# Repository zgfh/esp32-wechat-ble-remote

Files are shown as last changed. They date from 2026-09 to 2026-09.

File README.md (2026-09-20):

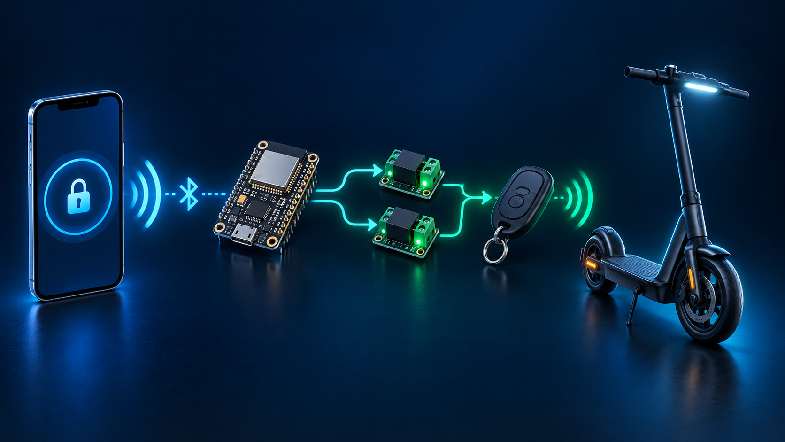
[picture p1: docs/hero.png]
微信小程序通过 BLE 控制 ESP32、光耦和电动车遥控器


<h1 align="center">电动车手机遥控钥匙</h1>
<p align="center"><strong>低成本、低复杂度：微信小程序 → BLE → ESP32 → 光耦 → 原装遥控器 → 电动车</strong></p>


> [!WARNING]
> 仅用于你有权控制的设备。项目只模拟原遥控器物理按键，不读取、复制或重放射频码；请勿接入一键启动等高风险功能。

## 你可能遇到的问题

你希望不用天天带物理遥控钥匙，却又不想拆解、复制或研究车辆的射频协议。若电动车后备箱本身是密码锁，可把这套设备与原遥控器一起放进后备箱：出门只带手机，需要时用小程序控制车辆。

本项目只做一件事：**以低成本、低复杂度保留原装遥控器的编码和发射能力，让 ESP32 通过光耦模拟真人短按。**

| 常见做法 | 本项目 |
| --- | --- |
| 复制或重放 RF，易遇滚动码问题 | 原遥控器继续处理 RF |
| ESP32 与遥控器共地 | 每个按键独立光耦隔离 |
| 蓝牙一连接就自动开锁 | 明确点按，避免瞬断误动作 |
| 设备名或 MAC 作为身份 | HMAC、随机挑战、序号防重放 |

### 推荐放置方式

```text
后备箱（密码锁）
├── 原装遥控器：仍负责滚动码和 RF 发射
└── ESP32 + 4 路光耦：由独立电源供电，连接遥控器按键焊盘

随身携带
└── 手机：微信小程序近距离 BLE 控制
```

后备箱密码是物理访问的第一道保护；请设置独立、可靠的密码，并妥善固定 ESP32 和遥控器，避免行驶震动导致接线松脱。

## 工作架构

完整工作原理图：手机、BLE、ESP32、光耦、原装遥控器和电动车

```mermaid
flowchart LR
  phone["📱 微信小程序\n输入密码 · 发起控制"] -->|"BLE"| esp["ESP32\nHMAC 验证 · 180 ms 脉冲"]
  esp -->|"GPIO 26 / 27 / 25 / 33"| opto["4 × PC817 光耦\n电气隔离"]
  opto -->|"模拟实体按键"| fob["原装遥控器\n滚动码 · RF 发射"]
  fob -->|"原装无线信号"| scooter["🛵 电动车"]
```

支持四路短按：**锁车、解锁、启动（闪电键）、寻车（喇叭键）**；同一时刻只允许一路输出。手机就是日常遥控入口，原装遥控器保留在后备箱内。

> 想了解信号边界、后备箱放置方式和安全部署顺序？阅读 [工作原理与部署指南](docs/working-principle.md)。

## 三分钟上手

### 1. 接线

每个按键使用独立 PC817：GPIO 经 330 Ω 接光耦 LED 输入；晶体管侧跨接遥控器对应的两块焊盘。

| 动作 | 普通 ESP32 | ESP32-S3 |
| --- | ---: | ---: |
| 锁车 | GPIO 26 | GPIO 4 |
| 解锁 | GPIO 27 | GPIO 5 |
| 启动 | GPIO 25 | GPIO 6 |
| 寻车 | GPIO 33 | GPIO 7 |

详细接线与测量方法见 [固件接线指南](firmware/README.md#接遥控器，同时保留-led当前接线图)。**遥控器侧绝不能与 ESP32 GND 相连，也不要用其纽扣电池为 ESP32 供电。**

### 2. 修改默认密码

[`firmware/pairing_config.py`](firmware/pairing_config.py) 的默认密码是 `dangerous`，仅供联调，公开可见且不安全。刷入前务必按需修改：

```python
BLE_PAIRING_SECRET = "替换为至少 32 位随机长密码"
```

随后在小程序密码框输入同一密码；密码不写入小程序源码或日志。这样即使有人在附近发现设备，也不能直接发送控制命令。

### 3. 刷入与连接

1. 上传 `firmware/main.py`、`firmware/security.py`、`firmware/pairing_config.py` 到 ESP32 MicroPython 根目录。
2. 微信开发者工具导入 [`miniprogram/`](miniprogram/)，真机预览并允许蓝牙/附近设备权限。
3. 连接 `ESP32-Car-Remote`，认证成功后使用按钮。

> 微信开发者工具不能模拟 BLE，必须在真实手机验证。

### 推荐：让 AI 协助安装、部署和运行

可把仓库链接、ESP32 板型和遥控器按键照片交给可信 AI 编程代理，让它协助检查引脚、生成随机密码、上传文件、运行测试和解释串口日志。

请明确要求 AI：**不提交真实密码、不猜测遥控器焊盘、未获确认前不触发车辆控制**。详见 [部署指南](docs/working-principle.md#推荐让-ai-协助部署)。

## 安全模型

```mermaid
sequenceDiagram
  participant P as 📱 小程序
  participant E as ESP32
  P->>E: HELLO2
  E-->>P: CHALLENGE2: 随机 nonce
  P->>E: AUTH2: HMAC(secret, nonce)
  E-->>P: AUTH_OK
  P->>E: CMD2: 序号 + 动作 + HMAC
  E-->>P: OK: 动作已接受
```

- 每连接独享挑战与认证，15 秒未认证自动断开。
- 每条命令绑定会话、动作和递增序号，防篡改与重放。
- 连续失败会冷却；5 分钟无操作自动断开。
- HMAC 不等同车规数字钥匙；更高要求应加入 BLE 加密、硬件安全元件和距离测量。

## 项目结构与测试

```text
firmware/       ESP32 MicroPython、接线资料、3D 外壳、回归测试
miniprogram/    微信小程序与 HMAC 安全测试
docs/hero.png   README 主视觉图
```

```bash
python3 -m unittest discover -s firmware/tests
node miniprogram/tests/security.test.js
```

## License

[MIT](LICENSE)

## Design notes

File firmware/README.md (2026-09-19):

# ESP32 BLE 遥控器控制端

> **安全协议 v2（已部署到普通 ESP32）**：必须同时更新 ESP32 的 `main.py`、`security.py` 和小程序代码，保留原有本地配对配置。旧 HELLO/AUTH/CMD 明文协议已停用；下方历史调试记录中的旧协议不能用于新版。

ESP32 通过 GPIO 输出（ESP32-S3：4/5/6/7；普通 ESP32：26/27/25/33） 180 ms 脉冲，驱动四个光耦，模拟原车遥控器的锁车/解锁/启动/寻车实体按键。它不会读取、复制或重放射频编码；遥控器仍完成原有编码和发射。

## 接遥控器，同时保留 LED（当前接线图）

VS Code 按 **⌘⇧V** 预览。以下适用于裸四脚 PC817，GPIO 编号按板上丝印识别。

四路遥控器按键与保留 LED 的隔离接线图

| 功能 | ESP32-S3 | 旧 ESP32 | 遥控器按键 |
| --- | --- | --- | --- |
| 锁车 | GPIO4 | GPIO26 | 锁车 / 设防 |
| 解锁 | GPIO5 | GPIO27 | 解锁 / 解防 |
| 启动 | GPIO6 | GPIO25 | 闪电键 |
| 寻车 | GPIO7 | GPIO33 | 喇叭键 |

每路 GPIO 分成两条并联支路：**GPIO → 330Ω → PC817 的 1 脚，2 脚 → ESP32 GND**；另一路 **GPIO → 独立 330Ω → 红色 LED 长脚，LED 短脚 → ESP32 GND**。不要让 LED 与光耦输入串联，也不要共用一个限流电阻。共需 4 颗 PC817、4 颗 LED、8 只 330Ω；建议各 GPIO 另加 10kΩ 到 GND。

**现有 LED 保留，但要从光耦输出侧移到 GPIO 侧。** 将光耦 3、4 脚原来接到 ESP32 GND / 3V3 / LED 的线路全部断开，再接遥控器；否则会破坏隔离。

### 圆形触点的测量方法与接线

照片中的每个按键由**中心圆点**和**外侧 C 形金属环**组成；按下时将两者接通。不能仅凭形状判断正负，也不能默认外圈是负极。

**本次用户实测：红表笔接中心、黑表笔接外圈，电压显示为正。因此已测按键的中心接 PC817 4 脚（集电极 C），外圈接 PC817 3 脚（发射极 E）。** 这里的“4 脚”是光耦脚号，不是 ESP32 GPIO4。该结论只针对已测触点，其他按键分别测量后再接。

1. **先断开 ESP32。** 遥控器只用原电池供电，不连接 ESP32 的 GND 或 3V3。
2. 万用表黑表笔插 **COM**，红表笔插 **VΩ**（不是电流插孔）；选择 **直流电压 V⎓**，量程高于电池标称电压，或使用自动量程。
3. 遥控器装好电池，按键保持松开。**红表笔接中心圆点，黑表笔接外圈 C 形环**。避免表笔同时碰到中心和外圈，以免模拟按键动作。
4. 根据下表确认接线。如果接近 0V、读数不稳定或正负跳变，先不要猜接，需要进一步确认电路或扫描方式。
5. 记录每个按键结果，**取下电池后再焊接**。两根线分别接中心和外圈，保留原按键；不要用焊锡把中心与外圈连在一起，也不要让线材妨碍原按键接触。

| 红笔中心、黑笔外圈时的读数 | PC817 4 脚（C）接 | PC817 3 脚（E）接 |
| --- | --- | --- |
| 稳定正数，例如 +3.0V（本次实测方向） | 中心圆点 | 外圈 C 形环 |
| 稳定负数，例如 −3.0V | 外圈 C 形环 | 中心圆点 |
| 接近 0V 或正负跳变 | 暂不接线，继续检查 | 暂不接线，继续检查 |

表中电压仅为示例，本次只确认了正负方向，未记录具体伏数。图中的 A 表示相对正端，B 表示相对负端；对本次已测按键，**A＝中心，B＝外圈**。三个按键各用独立 PC817，不能假定共用负端。LED 只证明 GPIO 发出指令，不代表光耦输出或车辆动作已经成功。

如果换成四脚机械按键：先取下电池，再用通断档找出“松开断路、按下导通”的两个有效触点；之后装电池，用直流电压档判断极性。**不要在带电时用通断档测量。**

PC817 脚号依据 [Sharp 数据表](https://www.learnabout-electronics.org/Downloads/PC817-optocoupler.pdf)。

<details><summary>旧版：仅 LED 测试接线图（不能直接并入遥控器）</summary>

旧测试线路

这张旧图将 LED 接在光耦输出端，输出侧使用 ESP32 电源，仅供无遥控器时测试。接遥控器请改为上方新图。

</details>

## BLE 协议与使用

1. 仓库随附 `pairing_config.py`，其默认密码 `dangerous` 仅供联调；用于真实设备前，必须按需改为至少 32 字符的随机密码。用户在小程序密码框输入相同内容。密码不再放入小程序源码或安装包。
2. 小程序扫描 `ESP32-Car-Remote`，连接服务 `6e400001-b5a3-f393-e0a9-e50e24dcca9e` 后订阅状态特征。
3. 小程序订阅成功后写入 `HELLO`；ESP32 对该连接发送 `CHALLENGE:<nonce>`。小程序写入 `AUTH:SHA256(secret:nonce)`，收到 `AUTH_OK` 后才发送 `CMD:LOCK` 或 `CMD:UNLOCK`。

挑战码和认证状态均按 BLE 连接隔离；断开连接后认证立即失效。设备应安装在受保护位置，且不应把默认示例密钥投入使用。

## Wokwi

图中 旧 ESP32 的 GPIO 26/27 各接一只 330 Ω 电阻和 LED，方便观察短按脉冲；实物请以光耦代替 LED。

协议现在以换行符结束每条消息，双向每包最多 20 字节，固件与小程序必须一起更新。认证挑战使用随机数且一次有效；默认占位密钥拒绝认证；三路按键不能同时输出。手机按钮的“已发送”仅表示 ESP32 接受指令，不代表车辆已经上锁。

本地主机回归测试：`python3 remote-key-web-controller/tests/test_protocol.py`（仓库根目录）。
2026-09-19 已经通过串口读取实物为 ESP32_GENERIC / MicroPython 1.28.0；这不代表新固件已刷入或手机 BLE 已验证。

## ESP32-S3 N8R2 实机刷写记录（2026-09-19）

- 串口：`/dev/cu.usbmodem1411201`；芯片 ESP32-S3 revision v0.2。
- 实测 Flash 8MB；内置 Quad PSRAM 2MB，固件识别成功。
- 已刷官方 `ESP32_GENERIC_S3-20260824-v1.29.0.bin` 标准版（不是 Octal PSRAM 版），写入地址 0，Flash 大小设置 8MB，写入哈希校验通过。
- 原 Flash 备份保存在本机 `/Users/zzg/.local/share/esp32-backups/20260919-s3/original-flash.bin`，不应公开上传。
- 已上传本项目 `main.py`；S3 自动使用 GPIO4 锁车、GPIO5 解锁，初始电平均为 0。BLE 初始化、GATT 注册和重启自动启动已实机验证。
- 后续已配置两端本地配对密钥，GPIO4 的 PC817 + LED 三次脉冲测试已由用户确认；手机 BLE 配对仍在调试中，尚未验证遥控器。
- 固件来源：https://micropython.org/download/ESP32_GENERIC_S3/
- S3 引脚限制：https://docs.espressif.com/projects/esp-idf/en/latest/esp32s3/api-reference/peripherals/gpio.html

## VS Code 串口日志

打开仓库根目录，按 **⌘⇧B** 运行 `ESP32: 重启程序并查看串口日志`。任务会自动选择唯一的 Espressif USB 串口，软重启程序并持续显示日志。若上一次日志任务仍在运行，先在其终端按 Ctrl+C 退出，再按快捷键重新启动。日志同时保存在根目录 `simulation-logs/esp32-日期-时间.log`。按 Ctrl+C 退出监视，板上程序继续运行。刷写前先关闭此任务，避免串口占用。

只想监听、不重启时，在“终端 → 运行任务”中选择 `ESP32: 查看串口日志（不重启）`。默认快捷键的重启操作会断开 BLE；随后的 `KeyboardInterrupt` 是工具主动中断旧程序的预期输出，等到 `BLE ready` 即表示重新启动成功。

启动成功显示 `BLE ready: ESP32-Car-Remote`；手机连上显示 `BLE: connected`；收到握手显示 `BLE: HELLO received`；验证成功显示 `BLE: authentication OK`。日志不输出配对密钥、挑战码或认证摘要。

小程序日志在微信开发者工具的真机调试 Console 中，筛选 `[BLE]`。`openBluetoothAdapter:fail` 表示手机蓝牙初始化失败，还没开始扫描 ESP32；记录 errCode、errno、errMsg 和 permission/system 日志再判断原因。代码更新后需重新加载手机测试版本。

### 增强诊断日志

日志前缀 `[ESP32 t=...ms]` 使用板子的运行计时，外层 `[时:分:秒]` 是电脑接收时间。

| 日志 | 含义 |
| --- | --- |
| BOOT / GPIO_READY | 板型、固件版本、重启原因、GPIO 和初始输出 |
| PAIRING_CONFIGURED True | 已配置配对密钥（不显示密钥） |
| BLE_ACTIVE / GATT_READY | BLE 开启与服务注册完成 |
| ADVERTISE_STARTED | 广播启动调用成功；不代表手机已扫描到 |
| HEARTBEAT | 每 10 秒输出 BLE 状态、连接数、认证数、空闲内存和 GPIO 电平 |
| CONNECTED / DISCONNECTED | 手机建立或断开连接 |
| RX_FRAGMENT / HELLO_RECEIVED | 收到分包长度和握手，不显示内容 |
| AUTH_OK / AUTH_FAILED | 认证结果 |
| NOTIFY_FAILED | 通知发送失败及错误码 |
| BUTTON_ON / BUTTON_OFF | 输出开始及释放，仅表示 GPIO 动作 |

连接数持续为 0 表示当时没有手机连入，不等于广播故障。日志队列最多 64 条，满后记录丢弃数；按键输出期间暂停打印，避免串口打印延迟释放。查看旧的“BLE: ...”阶段说明时，以这里的大写事件名为准。

## 启动（闪电键）

小程序新增“启动 ⚡”，通过 `CMD:START` 模拟一次 180ms 短按；必须验证成功后才能操作，与锁车、解锁三路互斥。发送成功只表示 GPIO 接受指令，不代表车辆已启动。若实体闪电键需要双击或长按，需另外调整。

ESP32-S3：锁车 GPIO4、解锁 GPIO5、启动 GPIO6；旧 ESP32：26、27、25。第三颗 PC817 的 1 脚经 330Ω 接 GPIO6，2 脚接 ESP32 GND；3、4 脚并联接遥控器闪电键触点，LED 按顶部新图保留在 GPIO 侧，遥控器与 ESP32 不共地。

## 手机 ESP32 日志窗口

小程序下方新增可展开、清空的日志窗口，保留最近 100 条。独立通知特征 `6e400004-b5a3-f393-e0a9-e50e24dcca9e` 只向已通过配对认证的连接发送日志；认证后补发最近 30 条已处理日志，再持续推送心跳、连接及按键事件。不是完整串口输出或持久化历史，重启前的记录不会保留。

日志每包最多 20 字节，每个主循环每个连接最多一包；有按键输出时暂停日志发送。队列有上限，积压时丢弃新日志并报告数量。日志不含密钥、挑战码或认证摘要。日志订阅失败不影响控制通道。

固件和手机代码均需更新。固件新增 GATT 特征后需断开重连；手机若找不到日志特征，可退出小程序重新打开以重新发现服务。未连接时的底层启动异常仍需通过 VS Code 串口查看。

## 中文日志

设备日志已改为中文：连接、身份验证、运行心跳及按键操作均用中文说明；旧文档中的 BOOT / AUTH_OK 等名称对应旧版日志。点击按钮会依次看到“收到手机指令：锁车”“正在模拟按下【锁车】键，持续 180 毫秒”“【锁车】按键已释放，输出已关闭（车辆状态未反馈）”。不再显示每个通信分包，以免淹没有用信息。

本次需要重新编译手机小程序并断开重连：日志按整行拼包后进行 UTF-8 解码，避免中文在蓝牙分包边界乱码。ESP32 已刷入中文日志固件；手机实际显示仍需真机确认。设备计时是板子单调计时，软重启不一定清零。

## 四路洞洞板与 3D 打印外壳

[永久接线图、焊接步骤、STL 与装配说明](hardware-v1/README.md)。电池供电及实物尺寸仍需确认，第四路固件暂未实现。

## 随时可连接的省电配置

当前源码保持 BLE 持续可连接，不调用 `machine.deepsleep()` 或 `machine.lightsleep()`。启动时明确关闭 Wi-Fi 客户端及热点；未连接广播间隔由 500ms 调整为 1 秒，心跳由 10 秒调整为 30 秒。发现设备可能稍慢，连接后按键仍使用原有 180ms 脉冲与 20ms 主循环，日志功能保留。

这只是降低不必要活动，不等同于已启用 ESP-IDF 蓝牙 Modem-sleep 或自动 Light-sleep；这些功能依赖固件构建配置。若 Wi-Fi 原本关闭，这项不会额外省电。整板省电幅度和电池续航尚未测量，板载电源灯、稳压器也会耗电。

本次修改时未检测到 USB 串口，省电版仅保存到本地，尚未上传或完成实机连接验证。

## 安全加固 v2

- 一个连接占用一个认证会话；未在连接后 15 秒内通过认证会断开，重复握手不延长超时。
- 使用 HMAC-SHA256 验证随机会话挑战；每条控制指令绑定该会话、动作名称和递增序号，拒绝篡改、重复及跨会话重放。不接受旧明文 CMD。
- 错误认证/非法指令清除会话并断开；累计 5 次失败后限制新会话 30 秒。冷却也会暂时影响合法用户，不能保证抵御持续无线干扰或恶意抢占。
- 同一连接每秒最多接收 40 个写入分包；超过限制断开。单条消息最多 128 字节。
- 已认证连接连续 5 分钟没有有效操作会断开；重新连接即可。广播持续开启，不需要实体按钮唤醒。
- 日志仅向认证连接发送；状态特征不再提供匿名读取。日志不包含密钥、挑战码、认证码或指令签名。

### 协议格式

`HELLO2` → `CHALLENGE2:<32位随机十六进制>` → `AUTH2:<HMAC(secret, auth:v2:nonce)>` → `AUTH_OK`。

控制指令：`CMD2:<序号>:<LOCK/UNLOCK/START/FIND>:<HMAC(secret, cmd:v2:nonce:序号:动作)>`，序号从 1 开始；即使按键忙而未执行，序号也会被消耗，避免重放。消息仍以换行结束、每包最多 20 字节。

### 仍存在的边界

本版没有启用 BLE 加密绑定，HMAC 提供指令完整性与认证，不提供保密性；无线监听者仍可能看到操作与日志，主动实时中继也不在本版防护范围内。小程序已改为用户输入密码，不再包含配对密钥文件；密码通过 `wx.setStorageSync` 保存在本机，打开页面自动填入；清空输入框可删除，关闭页面不删除存储。设备端密码仍在 `pairing_config.py`，实体板访问者可能提取。旧测试包曾包含旧密钥，正式使用前应更换设备密码。不要把防重放称为完整车辆防盗系统。

若继续加固，需要设计设备密码修改入口和 BLE 加密绑定，并在实际 iPhone 上验证；不能直接启用未经验证的配对选项导致现有手机无法连接。

验证：`python3 -m unittest discover -s remote-key-web-controller/tests`；`node remote-key-miniapp/tests/security.test.js`。HMAC 按 RFC 4231 及 Python/Node 标准实现交叉校验。当前 USB 板子是普通 ESP32，仅有 boot.py；原 S3 不在当前串口，未宣称已部署或通过手机实测。

## 当前实机：普通 ESP32（2026-09-19）

已将 `main.py`、`security.py`、新的 `pairing_config.py` 安装到普通 ESP32，运行 MicroPython 1.28.0。蓝牙广播、GATT 服务和默认低电平已实机确认；HMAC 标准向量、认证、重放、超时测试通过。新密码独立于旧 S3，未写入文档和小程序包。

**当前接线：GPIO26 锁车、GPIO27 解锁、GPIO25 启动、GPIO33 寻车。** 顶部当前接线图已同步，原 S3 图另存为 `docs/pc817-remote-led-wiring-s3.svg`（位于固件项目）。保留四路独立光耦，遥控器不与 ESP32 共地。

串口 `/dev/cu.wchusbserial141120`；VS Code 日志工具支持自动识别 CH340/CP210x 及原生 ESP32 USB，存在多个候选串口时需显式指定。重新编译手机小程序，在密码框输入新密码再连接。手机实际操作尚待验证。

## 寻车（喇叭键）

小程序“寻车 🔊”通过签名 FIND 指令模拟一次 180 毫秒短按，必须先验证密码，四路按键互斥。普通 ESP32 使用 GPIO33，S3 使用 GPIO7。GPIO33 经 330Ω 接第四颗 PC817 的 1 脚，2 脚接 ESP32 GND；3、4 脚并联到遥控器喇叭按键的两个有效触点，按上面的测量方法判断方向。LED 保留在 GPIO 侧，并单独串联 330Ω。焊接前断开 USB 和遥控器电池。

需同步更新 main.py、security.py 和小程序代码；配对密码不变。发送成功只表示模拟按键，不代表车辆实际响应。实际喇叭键是否寻车、是否需要长按，应以原遥控器实测为准。

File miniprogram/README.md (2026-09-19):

# 微信小程序 BLE 遥控端

## 使用方法

1. 在微信开发者工具导入本目录，重新编译并打开手机测试版。
2. 在“设备配对密码”输入框填写 ESP32 上 `pairing_config.py` 中配置的相同密码（至少 32 个字符，建议随机生成）。
3. 点击“连接 ESP32”，验证成功后使用锁车、解锁或启动按钮。
4. ESP32 日志窗口会补发近期记录并继续显示中文日志，可展开、清空。

密码按用户要求通过 `wx.setStorageSync` 保存在本机小程序存储，键名为 `remoteKey.pairingPassword.v1`；下次打开自动回填。清空输入框时通过 `wx.removeStorageSync` 删除。页面关闭仅清除内存变量，不删除本地存储。存储不是系统钥匙串，不额外加密；密码不写入日志、不随小程序包发布。连接过程中及连接成功后不能修改密码，需先断开。输入框不会修改 ESP32 的设备密码。

旧 `pairing.local.js` 已移出项目目录，打包配置也明确排除该文件及测试目录。之前生成的小程序包仍可能含旧密钥，删除源码不能撤销旧包；正式使用前应更换设备密码并停止使用旧测试包。

## 安全协议 v2

安全版已部署到普通 ESP32（MicroPython 1.28.0）；原 S3 未同步更新。需要同时更新设备的 `main.py`、`security.py`，并保留 `pairing_config.py`。旧版设备不能与新版小程序认证，不做降级兼容。

使用 HMAC-SHA256 验证随机会话挑战，每条指令绑定会话、递增序号及操作内容，拒绝篡改和重放。15 秒内未完成认证会断开；累计 5 次失败后冷却 30 秒；已认证会话 5 分钟没有有效操作会断开，重新连接即可。

本版尚未启用 BLE 链路加密绑定；操作和日志不保密，也不防实时中继。设备密码仍存储在板上普通文件中，实体访问仍有风险。短弱密码可能被离线猜测，因此保留至少 32 字符的要求。

## 日志与接线

开发者工具真机调试 Console 筛选 `[BLE]` 可看手机连接阶段，但不会输出密码和签名。蓝牙日志每包最多 20 字节，按整行 UTF-8 解码，保留最近 100 条。

遥控器和 LED 接线

[完整接线及触点测量方法](../remote-key-web-controller/README.md#圆形触点的测量方法与接线)。当前 S3：GPIO4 锁车、GPIO5 解锁、GPIO6 启动。LED 保留在 GPIO 侧，遥控器通过 PC817 隔离，不与 ESP32 共地。

## 验证

在仓库根目录运行 `node remote-key-miniapp/tests/security.test.js` 和 `python3 -m unittest discover -s remote-key-web-controller/tests`。

## 当前实机：普通 ESP32（2026-09-19）

已将 `main.py`、`security.py`、新的 `pairing_config.py` 安装到普通 ESP32，运行 MicroPython 1.28.0。蓝牙广播、GATT 服务和默认低电平已实机确认；HMAC 标准向量、认证、重放、超时测试通过。新密码独立于旧 S3，未写入文档和小程序包。

**当前接线：GPIO26 锁车、GPIO27 解锁、GPIO25 启动。** 顶部当前接线图已同步，原 S3 图另存为 `docs/pc817-remote-led-wiring-s3.svg`（位于固件项目）。保留三路独立光耦，遥控器不与 ESP32 共地。

串口 `/dev/cu.wchusbserial141120`；VS Code 日志工具支持自动识别 CH340/CP210x 及原生 ESP32 USB，存在多个候选串口时需显式指定。重新编译手机小程序，在密码框输入新密码再连接。手机实际操作尚待验证。

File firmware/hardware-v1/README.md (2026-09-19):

# 四路 PC817 洞洞板电路与打印外壳

四路接线图

此版依据最新照片：黑色长开发板、标注 5CM×7CM 的洞洞板、4 个 PC817、4 个 LED、4 个按钮。绿色遥控器裸板及双节电池座也预留空间。照片上的元件只有摆放，背面未焊，因此图是建议接法，不是现有线路复原。板上白色网格不是铜线连通证据。

## 永久电路，每路相同

| 连接 | 元件/端点 |
|---|---|
| 输入 | GPIO → 330Ω → PC817 1 脚 |
| 输入回路 | PC817 2 脚 → ESP32 GND |
| 指示灯支路 | 同一 GPIO → 1kΩ → LED 阳极；LED 阴极 → ESP32 GND |
| 上电下拉 | GPIO → 10kΩ → ESP32 GND |
| 隔离输出 | PC817 4 脚 → 遥控器有效触点 A；3 脚 → 触点 B |
| 手动操作 | 常开按钮两有效端分别接同一路 A、B |

红外 LED 和可见 LED 不能直接并联共用电阻。330Ω 光耦支路在 3.3V 下约 6mA（按约 1.2V 压降估算）；1kΩ 为低电流指示用途，不同颜色亮度不同，蓝灯可能较暗。GPIO 直接驱动方案需确认使用 3.3V ESP32 及其引脚能力。

**按钮直接操作遥控器，不经过认证和固件互斥，也不限制按下时长。** 默认上盖不开操作孔，以便开盖维护；如需外部手动操作，再实测开孔位置并确认此行为适合你。四路遥控器触点各自保留两根独立线，禁止根据猜测合并地线。

照片看起来有 7 只电阻，四路完整永久电路需要 12 只：330Ω×4、1kΩ×4、10kΩ×4。按万用表实测阻值确认，不能从照片可靠判定每只阻值。使用绝缘细导线，不要让输入与输出之间的背面锡桥跨接。

## 引脚与固件对应

| 通道 / 照片从上到下 | 普通 ESP32 | ESP32-S3 | 当前状态 |
|---|---|---|---|
| 红 / 锁车 | 26 | 4 | 已有固件通道 |
| 绿 / 解锁 | 27 | 5 | 已有固件通道 |
| 黄 / 第三功能 | 25 | 6 | 固件名 start，具体遥控器按键先核实 |
| 蓝 / 预留 | 暂不接 GPIO | 暂不接 GPIO | 固件未实现；输入通过 10kΩ 接地 |

最新照片 VP、VN、34、35 等丝印更像普通 ESP32。此为外观判断，不能替代实际芯片确认；不要对 S3 使用普通 ESP32 那一列。GPIO 编号不是物理针脚序号。本次没有修改固件或刷板。

## 按这个顺序焊接与检查

1. 拔掉 USB 和电池。用器件圆点/缺口及对应厂家资料确认 PC817 1/2/3/4 脚；从背面看，左右镜像，不要凭正面照片直接套背面孔位。
2. 每路先焊 330Ω→1 脚、2 脚→输入 GND。再焊独立 LED 支路、10kΩ 下拉。将每路 GPIO 输入引到独立端子，第四路只预留。
3. 用通断档识别四脚按钮：取松开断路、按下才通的一对。很多按钮同侧两脚已经永久相通，选错会一直短接输出。
4. 把按钮这两端与同一路 PC817 4/3 脚分别并联，引出 A/B。断电检查输入 GND 与任何 A/B 都不应有金属直连；按按钮时只有对应 A/B 接通。
5. 遥控器暂不接入。用临时测试负载 `ESP32 3V3 → 330Ω → 红色测试 LED → 4脚，3脚 → ESP32 GND`，一次测试一路光耦输出。该临时回路与永久输入指示 LED 不是同一支路。
6. 测试后完全拆除临时输出侧 LED/3V3/GND 接线。遥控器断电时识别按键触点对，恢复原供电后测 A/B 极性，4 脚接相对正端、3 脚接相对负端。若电压随扫描变动或极性不稳定，应先查清，不直接连接。原板的圆形触点需焊到实际铜焊盘/走线，不直接在碳膜接触面堆锡。

## 供电尚待电池信息

目前电路只确定 ESP32 由 USB 供电、遥控器保持其原电源且与 ESP32 不共地。双节电池座只做机械预留；照片不能确定电池化学体系、实际电压、电池座串并联及该板的电池接口功能。**不要把电池座直接接 3V3 或未知白色接口，也不要假定板载充电支持这组电池。** 提供电池标注/电压后再完成电源与开关部分。

## 外壳

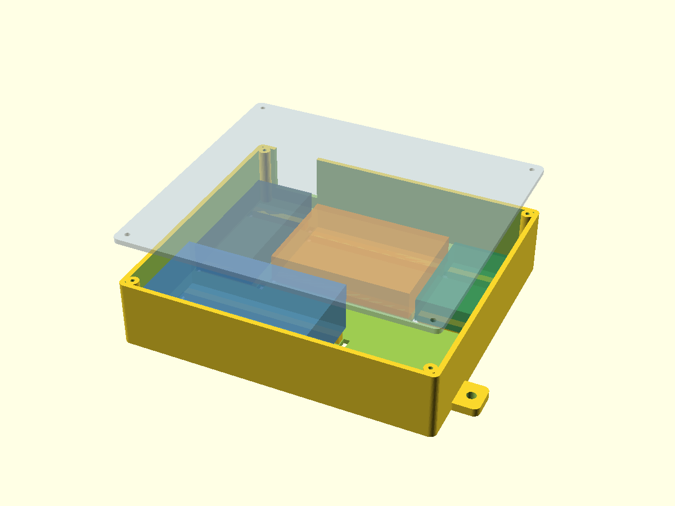
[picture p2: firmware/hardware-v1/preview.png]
装配预览


[源文件](controller-case.scad) · [底盒 STL](case-bottom.stl) · [上盖 STL](case-lid.stl)

默认盒身 **150.8×134.8×34.8 mm**，含安装耳总宽 174.8 mm。这是保守的并排安装版，便于焊接和维护，没有把开发板压在洞洞板背面的焊点上。

| 区域 | 占位尺寸 mm | 依据 |
|---|---|---|
| ESP32 黑板 | 30×65×14 | 假设，含接口/焊点需实测 |
| 洞洞板 | 70×50×14 | 70×50 来自照片标称；厚度/元件高假设 |
| 遥控器裸板 | 30×50×12 | 假设，背面未知 |
| 双节电池座 | 80×40×24 | 假设，需实测装电池后的包络 |
| 可选电源小板空间 | 35×28×15 | 仅空间预留，无电源方案定型 |

底部支撑高 4mm；用绝缘垫和扎带固定，支撑条位置可在 SCAD 修改。支撑必须避开底部器件，扎带不能压遥控器触点。扎带穿底部槽，若安装面会压住扎带，安装时在安装耳下加垫片保持空隙。未猜测板上螺丝孔距。

USB 面向 +Y 壁，预留大线缆缺口，使用延长线，非精确插座配合。四角 M2.5 自攻螺丝（建议先试 M2.5×10），底盒孔 2.0mm、上盖孔 2.6mm；材料与打印机会影响配合。侧面安装耳 M4 通孔 4.5mm。

默认上盖不打 LED/按钮孔，因其精确中心和高度未测；可按实测启用 `access_holes` 并修改数组，圆孔仅是访问孔，没有会意外压住按钮的顶杆。当前并非带外部按键帽的成品。电池与电路天线之间也应留空，实测无线效果。

底盒平底朝下、上盖平面朝下分别打印。建议初始 0.2mm 层高、至少 3 圈外壁；按安装环境选择材料。无防水设计。先局部试印固定孔及支撑，测量确认后再印整盒。

## 验证与复现

`build_design.py` 生成 SCAD、SVG 与 `netlist.json`，并检查端子唯一性、输出网连接范围、SVG XML。它不是电路仿真或 PCB 布线验证。OpenSCAD 导出检查记录见本次交付；即便网格通过，也不代表实物适配。

```sh
openscad -D 'part="bottom"' -o case-bottom.stl controller-case.scad
openscad -D 'part="lid"' -o case-lid.stl controller-case.scad
openscad -D 'part="assembly"' --autocenter --viewall --imgsize=1200,900 -o preview.png controller-case.scad
```

资料：[Sharp PC817 数据表](https://global.sharp/products/device/lineup/data/pdf/datasheet/PC817XxNSZ1B_e.pdf)、[Espressif ESP32 GPIO 文档](https://docs.espressif.com/projects/esp-idf/en/latest/esp32/api-reference/peripherals/gpio.html)。

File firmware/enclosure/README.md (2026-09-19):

# 遥控器控制器外壳（尺寸待确认草稿）

适用方案：ESP32-S3、PC817 焊接板、保留原电池的遥控器并排放置。源文件为 `case.scad`，独立于固件，不涉及 Wokwi 部署。

**此版本不能直接视为实物适配完成。** N8R2 仅说明存储配置，不能确定开发板的长宽、USB 位置或安装孔。以下尺寸是设计占位值，不是厂家数据。

| 模块 | 假设安装包络：长×宽×高（mm） |
|---|---|
| ESP32，含排针及底部焊点 | 65×30×18 |
| 光耦洞洞板 | 40×30×15 |
| 遥控器，保留原外壳及电池 | 65×38×20 |

按这些参数，盒体约 87.8×136.8×33.8 mm，安装耳使总长约 111.8 mm。`include_remote=false` 可移除遥控器舱。为便于修改采用并排布局，实测后可缩小。

## 结构与装配

- 底盒＋平面上盖，四角 M2.5 自攻螺丝。上盖孔 2.6 mm、底盒盲孔 2.0 mm；建议试配 M2.5×10，勿强行拧入。四根螺柱连到底板。
- 每模块有两根 4 mm 高支撑条；底部穿扎带孔，把模块绑在支撑条上。裸板需按实物焊点位置调整支撑条，并加绝缘垫；不能让支撑顶住元件、短接焊点或压住遥控器按键。
- 两侧安装耳开 4.5 mm 通孔，便于用 M4 螺钉安装；装配前先固定底盒，再装电子模块。
- 侧面顶部留 18×10 mm 线缆缺口，适合将 USB 延长线引出，**并非按实测位置设计的 USB 插座孔**。线缆在盒内另加扎带固定，避免拉扯接口。
- 遥控器维持自己的电池与绝缘；支撑条和扎带不得压天线。天线附近尽量不放螺丝、导线束或金属支架。
- 该版本有底部绑带孔和开放线缆口，无防水等级；安装环境确认后再决定密封、排水和固定形式。

## 定稿前测量

1. ESP32 板长宽、总高（含排针和焊点）、USB 插头插入后的空间、天线方向。
2. 光耦最终用洞洞板还是模块，其长宽高；不要按临时面包板估算成品。
3. 遥控器外壳长宽高、按键及电池盖的位置；是否整个装入本盒。
4. 安装空间和固定面孔距，以及是否有雨水、日晒、车辆振动。

## 打印与导出

底盒底面朝下，上盖平面朝下，各自独立打印；建议初始层高 0.2 mm、至少 3 圈外壁。材料按实际环境选择，先打印安装孔及支撑局部试配，再打印整盒。

当前环境未发现 OpenSCAD，尚未生成 STL 或完成渲染/网格验证。模型仅依赖 OpenSCAD 核心功能，无 BOSL2。macOS 安装命令供参考（未执行）：`brew install --cask openscad`。

安装后在本目录执行：

```sh
openscad -D 'part="bottom"' -o case-bottom.stl case.scad
openscad -D 'part="lid"' -o case-lid.stl case.scad
openscad -D 'part="assembly"' --viewall --autocenter --imgsize=1200,900 -o preview.png case.scad
```

导出后需检查所有警告、预览中的孔位和支撑条，再做实物试装。

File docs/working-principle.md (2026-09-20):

# 工作原理与完整部署指南

手机、ESP32、光耦、原装遥控器与电动车的工作架构

## 工作原理

手机只通过 BLE 向 ESP32 发出经过认证的控制请求。ESP32 验证 HMAC 后，对相应 GPIO 输出 180 ms 脉冲；PC817 的晶体管侧模拟原遥控器按键。遥控器仍用自身电池、滚动码与 RF 模块控制车辆，因此无需研究或复制 RF 协议。

设备和原遥控器可固定在密码锁后备箱中；ESP32 与遥控器不共地，并使用独立电源。

## 0. 需要准备

- ESP32 DevKit（普通 ESP32 或 ESP32-S3）、数据 USB 线、电脑。
- 4 路 PC817、8 个 330 Ω 电阻、绝缘导线与独立 ESP32 电源。
- 已安装 Python 3.10+；首次刷写会清空 ESP32 flash 中的已有文件。

## 1. 安装电脑工具

在终端执行：

```bash
python3 -m pip install --upgrade esptool mpremote
git clone https://github.com/zgfh/esp32-wechat-ble-remote.git
cd esp32-wechat-ble-remote
```

macOS 可用 `ls /dev/cu.*` 查找串口；Linux 常见为 `/dev/ttyUSB0` 或 `/dev/ttyACM0`；Windows 常见为 `COM3` 之类。下文将它替换为 `PORT`。

## 2. 下载正确的 MicroPython 固件

从官方页面下载最新**稳定版** `.bin`：

| 板型 | 官方下载页 | 备注 |
| --- | --- | --- |
| 普通 ESP32/WROOM | [ESP32_GENERIC](https://micropython.org/download/ESP32_GENERIC/) | 绝大多数 4MB+ 普通 ESP32 |
| ESP32-S3 | [ESP32_GENERIC_S3](https://micropython.org/download/ESP32_GENERIC_S3/) | 有 Octal PSRAM 时选择页面中的 spiram-oct 变体 |

不要下载 ESP32-S2 固件：它没有 BLE。若不确定芯片型号，先查看开发板丝印或让 AI 根据照片协助确认。

## 3. 擦除并刷入固件

按住开发板的 **BOOT** 键并插入 USB（部分板不需要），然后：

```bash
# 普通 ESP32：替换 PORT 和下载的文件名
esptool --chip esp32 --port PORT erase_flash
esptool --chip esp32 --port PORT --baud 460800 write_flash 0x1000 ESP32_GENERIC-xxxx.bin
```

S3 请把 `--chip esp32` 改为 `--chip esp32s3` 并使用下载页给出的烧录地址。若 460800 波特率失败，移除 `--baud 460800` 后重试。官方 ESP32 通用固件刷写地址为 `0x1000`；请始终以你下载的板型页面说明为准。

## 4. 配置密码并上传程序

编辑 `firmware/pairing_config.py`。默认 `dangerous` 仅用于联调，实际使用前必须改成至少 32 字符随机密码：

```python
BLE_PAIRING_SECRET = "替换为随机长密码"
```

上传三个文件；这会在设备根目录创建/替换同名文件：

```bash
mpremote connect PORT fs cp firmware/main.py :main.py
mpremote connect PORT fs cp firmware/security.py :security.py
mpremote connect PORT fs cp firmware/pairing_config.py :pairing_config.py
mpremote connect PORT reset
mpremote connect PORT repl
```

串口看到 `BLE ready` 与广播日志即表示固件已启动。先不要接遥控器，先用 LED/光耦输入侧确认四路 GPIO 脉冲正确。

## 5. 导入微信小程序

1. 用微信开发者工具导入仓库 `miniprogram/` 目录，使用自己的 AppID 或测试号。
2. 真机预览，允许蓝牙与附近设备权限。
3. 搜索 `ESP32-Car-Remote`，在密码框输入第 4 步的同一密码。
4. 等待“已验证”，再测试按钮。开发者工具本身不能模拟 BLE。

## 推荐让 AI 协助安装、部署和运行

推荐把本仓库链接、你的操作系统、ESP32 板型和遥控器按键照片交给可信 AI 编程代理。它可以协助选择固件、生成命令、检查串口、上传文件、运行测试和解释日志。

请明确要求 AI：**不提交真实密码、不猜测遥控器焊盘、未获确认前不触发车辆控制**。焊接前必须由你用万用表验证每一组触点。

## 排查

| 症状 | 优先检查 |
| --- | --- |
| `Failed to connect` | 换数据线；按住 BOOT；确认串口与芯片参数 |
| 刷写中断 | 去掉高速波特率后重试 |
| 手机找不到设备 | 重启板子；确认下载的是 BLE 支持的 ESP32/ESP32-S3 固件 |
| 小程序认证失败 | 两端密码是否完全相同；默认 `dangerous` 是否已被修改 |
| GPIO 正常但车辆无响应 | 断电后用万用表确认按键焊盘和 PC817 输出侧，不要接 ESP32 GND |

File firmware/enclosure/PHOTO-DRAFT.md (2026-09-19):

# 照片版：裸遥控器板并排外壳草稿

模型：[case-photo-draft.scad](case-photo-draft.scad)。原模型保留，照片版独立修改。

选用照片中央的绿色遥控器裸板、其下黑色开发板，以及尚待制作的两路 PC817 焊接小板；未纳入面包板、照片下方彩色小板或散放的电池。此组合等待用户确认。

## 占位尺寸，必须实测后再打印

| 部件 | 长×宽×安装总高 mm |
|---|---|
| 黑色开发板 | 55×30×12 |
| PC817 焊接板 | 25×20×12 |
| 绿色遥控器裸板 | 45×30×10 |

这些数值是建模假设，照片没有可靠比例尺。盒身约 77.8×118.8×25.8 mm，含安装耳总长约 101.8 mm。没有电池舱，不代表已解决遥控器供电。

三块板并排，避免上下叠放挡住天线；底部支撑高 4 mm，配绝缘垫与扎带。遥控器接触面朝上，盖子不设按压柱，避免误触；此版不支持隔着外壳手动按键。实际扎带不得横压触点或元件，需要看板背面后再定位支撑。裸 PCB 不能直接以固定尺寸草稿宣称适配。

USB 端采用 26 mm 宽、19 mm 深的顶部开口，给调试线引出使用，不是精确双 USB 插座孔。安装耳沿侧面移开，避免挡住线缆出口。四角 M2.5 自攻螺丝固定平盖。底盒及平盖均底面朝下打印。

待补充：两块板的长宽、正反面最高元件高度、USB 外沿位置、遥控器电池及电池座布局、是否保留手动按键，以及外壳固定位置。若要连面包板或电池一起装入，需重新规划尺寸。

当前没有可用 OpenSCAD，因此尚无 STL、渲染图或网格验证。可将模型全文复制到 OpenSCAD 网页编辑器预览，part="assembly" 看装配，part="bottom" 看底盒，part="lid" 看上盖。彩色占位块不导出到零件 STL。

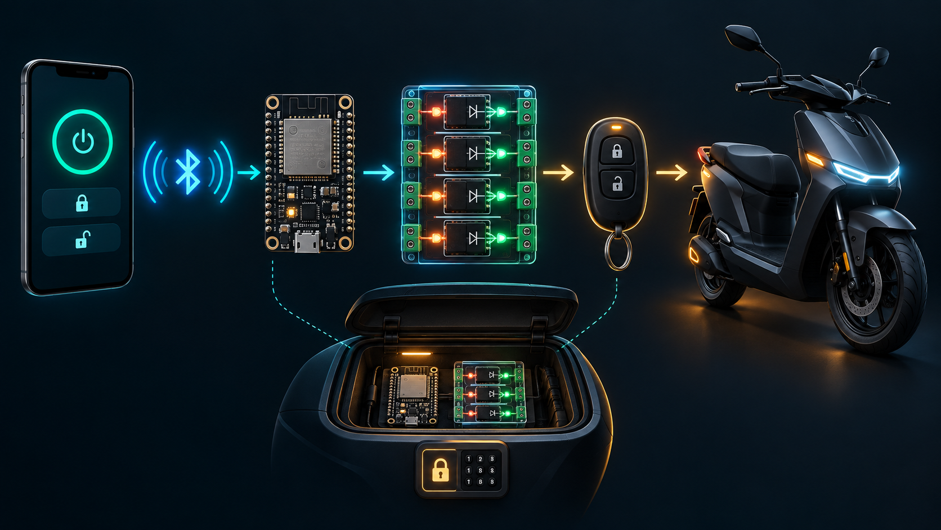
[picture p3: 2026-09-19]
docs/working-principle.png

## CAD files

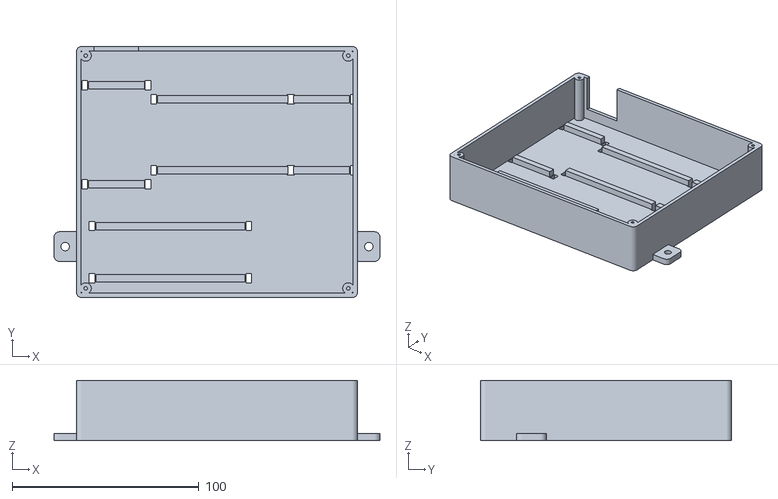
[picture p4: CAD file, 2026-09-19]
firmware/hardware-v1/case-bottom.stl
174.8 x 134.8 x 32.4

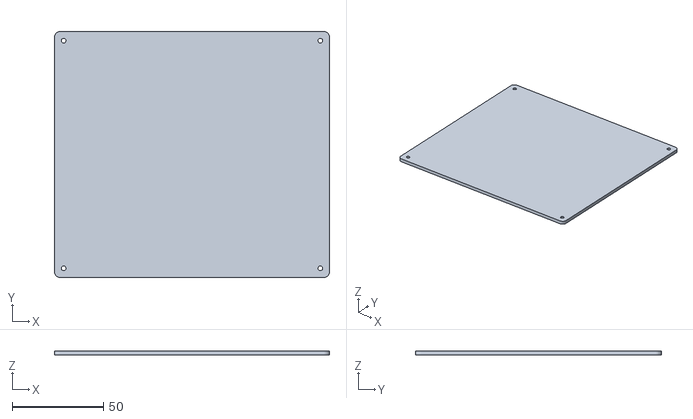
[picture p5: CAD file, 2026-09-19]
firmware/hardware-v1/case-lid.stl
150.8 x 134.8 x 2.40

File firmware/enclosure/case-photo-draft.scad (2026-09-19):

/* Adapted from openscad-enclosure/assets/esp32_case_template.scad.
   PHOTO DRAFT: central black board + bare green remote PCB + future opto perfboard.
   Dimensions are UNMEASURED placeholders, not inferred physical measurements. */
$fn=48;
part="assembly"; // bottom, lid, layout, assembly
// UNMEASURED hardware envelopes INCLUDING underside joints. Confirm before printing.
esp_size=[55,30,12];
opto_size=[25,20,12];
remote_size=[45,30,10];
include_remote=true;
clearance=3;
module_gap=8;
wall=2.4;
floor_thickness=2.4;
lid_thickness=2.4;
corner_radius=3;
headroom=5;
support_height=4;
support_width=5;
support_edge_inset=7;
// Cable ties wrap around module + support rails through bottom slots.
tie_slot_width=3;
tie_slot_length=5;
tie_edge_margin=3;
// Four M2.5 self-tapping screws. Pilot must be tuned on a printed sample.
screw_clearance=2.6;
screw_pilot=2.0;
boss_diameter=6;
boss_offset=5;
pilot_depth=12;
// Broad cable exit, open at top for easy cable installation. Not watertight.
cable_opening_width=26;
cable_opening_depth=19;
cable_opening_y=-38; // Align broad exit with ESP row; change after measuring connectors.
// External mounting tabs, M4 screw holes.
ear_width=14;
ear_projection=12;
ear_thickness=4;
ear_hole=4.5;
exploded_gap=18;
layout_gap=15;
show_hardware=true;

sizes=include_remote?[esp_size,opto_size,remote_size]:[esp_size,opto_size];
inner_length=max([for(s=sizes)s[0]])+2*clearance+2*boss_diameter;
inner_width=esp_size[1]+opto_size[1]+(include_remote?remote_size[1]:0)+(len(sizes)-1)*module_gap+2*clearance+2*boss_diameter;
outer_length=inner_length+2*wall;
outer_width=inner_width+2*wall;
bottom_height=floor_thickness+support_height+max([for(s=sizes)s[2]])+headroom;
function sum_before(i)=i==0?0:sizes[i-1][1]+module_gap+sum_before(i-1);
function cy(i)=-inner_width/2+clearance+boss_diameter+sum_before(i)+sizes[i][1]/2;
module rounded_box(size,r){linear_extrude(size[2])offset(r=r)square([size[0]-2*r,size[1]-2*r],center=true);}
module screws(){for(x=[-1,1],y=[-1,1])translate([x*(outer_length/2-boss_offset),y*(outer_width/2-boss_offset),0])children();}
module bottom_case(){difference(){union(){
 difference(){rounded_box([outer_length,outer_width,bottom_height],corner_radius);translate([0,0,floor_thickness])rounded_box([inner_length,inner_width,bottom_height],max(.1,corner_radius-wall));}
 screws()cylinder(h=bottom_height,d=boss_diameter);
 for(i=[0:len(sizes)-1],side=[-1,1])translate([side*(sizes[i][0]/2-support_edge_inset),cy(i),floor_thickness+support_height/2-.05])cube([support_width,sizes[i][1],support_height+.1],center=true);
 for(side=[-1,1])translate([side*(outer_length/2+ear_projection/2-wall/2),20,0])rounded_box([ear_projection+wall,ear_width,ear_thickness],corner_radius);
 }
 screws()translate([0,0,max(floor_thickness,bottom_height-pilot_depth)])cylinder(h=pilot_depth+1,d=screw_pilot);
 for(side=[-1,1])translate([side*(outer_length/2+ear_projection/2),20,-1])cylinder(h=ear_thickness+2,d=ear_hole);
 translate([-outer_length/2,cable_opening_y,bottom_height-cable_opening_depth/2+.5])cube([wall*3,cable_opening_width,cable_opening_depth+1],center=true);
 for(i=[0:len(sizes)-1],xside=[-1,1],yside=[-1,1])translate([xside*(sizes[i][0]/2-support_edge_inset),cy(i)+yside*(sizes[i][1]/2+tie_edge_margin),floor_thickness/2])cube([tie_slot_length,tie_slot_width,floor_thickness+2],center=true);
}}
// Flat lid: no unverified snap fits or lip/boss intersections.
module lid(){difference(){rounded_box([outer_length,outer_width,lid_thickness],corner_radius);screws()translate([0,0,-1])cylinder(h=lid_thickness+2,d=screw_clearance);}}
module hardware(){for(i=[0:len(sizes)-1])color(i==0?"SeaGreen":i==1?"orange":"DimGray",.5)translate([0,cy(i),floor_thickness+support_height+sizes[i][2]/2])cube(sizes[i],center=true);}
assert(screw_pilot<screw_clearance);
assert(module_gap>2*tie_edge_margin+tie_slot_width/2);
echo(outer_dimensions=[outer_length,outer_width,bottom_height+lid_thickness]);
if(part=="bottom")bottom_case();
else if(part=="lid")lid();
else if(part=="layout"){bottom_case();translate([0,outer_width+layout_gap,0])lid();}
else{bottom_case();if(show_hardware)hardware();translate([0,0,bottom_height+exploded_gap])color("LightSteelBlue")lid();}

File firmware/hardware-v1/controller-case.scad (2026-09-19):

// Four-channel controller enclosure. Hardware envelopes are assumptions except nominal 70x50 perfboard.
$fn=48;
part="assembly"; // bottom, lid, layout, assembly
wall=2.4; floor_t=2.4; lid_t=2.4; corner_r=3;
inner_x=146; inner_y=130; cavity_h=30;
// Positions are XY centers. Total height includes underside solder / headers.
board_sizes=[[30,65,14],[70,50,14],[30,50,12],[80,40,24],[35,28,15]];
board_positions=[[-54,20],[3,20],[56,20],[-25,-43],[49,-43]];
// 0 ESP32; 1 perfboard; 2 remote PCB; 3 existing battery holder; 4 optional power module space.
show_power_module=false;
support_h=4; support_w=4; support_inset=6;
tie_slot_x=3; tie_slot_y=5; tie_edge_gap=2;
screw_clearance=2.6; screw_pilot=2.0; boss_d=6; boss_offset=5; pilot_depth=12;
ear_projection=12; ear_width=16; ear_h=4; ear_hole=4.5; ear_y=-40;
// Cable notch on +Y wall, aligned with ESP area. USB extension, not a fitted socket opening.
usb_x=-54; usb_width=24; usb_depth=23;
exploded_gap=22; layout_gap=15; show_hardware=true;
// Optional lid access requires MEASURED coordinates. Disabled until measured.
access_holes=false;
button_centers=[[25,39],[25,26],[25,13],[25,0]];
led_centers=[[8,39],[8,26],[8,13],[8,0]];
button_access_d=10; led_access_d=6;
eps=.05;
outer_x=inner_x+2*wall; outer_y=inner_y+2*wall; bottom_h=floor_t+cavity_h;
module rounded_box(s,r){linear_extrude(s[2])offset(r=r)square([s[0]-2*r,s[1]-2*r],center=true);}
module screw_positions(){for(x=[-1,1],y=[-1,1])translate([x*(outer_x/2-boss_offset),y*(outer_y/2-boss_offset),0])children();}
module supports(){for(i=[0:3],side=[-1,1])translate([board_positions[i][0],board_positions[i][1]+side*(board_sizes[i][1]/2-support_inset),floor_t-eps])linear_extrude(support_h+eps)square([board_sizes[i][0],support_w],center=true);}
module tie_slots(){for(i=[0:3],side=[-1,1],end=[-1,1])translate([board_positions[i][0]+side*(board_sizes[i][0]/2+tie_edge_gap),board_positions[i][1]+end*(board_sizes[i][1]/2-support_inset),-eps])linear_extrude(floor_t+2*eps)square([tie_slot_x,tie_slot_y],center=true);}
module bottom_case(){difference(){union(){
 difference(){rounded_box([outer_x,outer_y,bottom_h],corner_r);translate([0,0,floor_t])rounded_box([inner_x,inner_y,bottom_h],max(.1,corner_r-wall));}
 screw_positions()cylinder(h=bottom_h,d=boss_d);
 supports();
 for(side=[-1,1])translate([side*(outer_x/2+ear_projection/2-wall/2),ear_y,0])rounded_box([ear_projection+wall,ear_width,ear_h],corner_r);
 }
 screw_positions()translate([0,0,bottom_h-pilot_depth])cylinder(h=pilot_depth+eps,d=screw_pilot);
 tie_slots();
 for(side=[-1,1])translate([side*(outer_x/2+ear_projection/2),ear_y,-eps])cylinder(h=ear_h+2*eps,d=ear_hole);
 translate([usb_x,outer_y/2,bottom_h-usb_depth/2+eps])cube([usb_width,wall*3,usb_depth+2*eps],center=true);
}}
module lid(){difference(){rounded_box([outer_x,outer_y,lid_t],corner_r);screw_positions()translate([0,0,-eps])cylinder(h=lid_t+2*eps,d=screw_clearance);
 if(access_holes){for(p=button_centers)translate([p[0],p[1],-eps])cylinder(h=lid_t+2*eps,d=button_access_d);for(p=led_centers)translate([p[0],p[1],-eps])cylinder(h=lid_t+2*eps,d=led_access_d);}
}}
module hardware(){for(i=[0:show_power_module?4:3])color(i==0?"DarkSlateGray":i==1?"DarkOrange":i==2?"SeaGreen":"SteelBlue",.65)translate([board_positions[i][0],board_positions[i][1],floor_t+support_h])linear_extrude(board_sizes[i][2])square([board_sizes[i][0],board_sizes[i][1]],center=true);}
assert(cavity_h>=support_h+max([for(s=board_sizes)s[2]])+2,"Increase cavity height");
assert(bottom_h-pilot_depth>floor_t);
echo(body=[outer_x,outer_y,bottom_h+lid_t]);
if(part=="bottom")bottom_case();else if(part=="lid")lid();else if(part=="layout"){bottom_case();translate([0,outer_y+layout_gap,0])lid();}else{bottom_case();if(show_hardware)hardware();translate([0,0,bottom_h+exploded_gap])color("LightSteelBlue",.5)lid();}

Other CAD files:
firmware/enclosure/case.scad

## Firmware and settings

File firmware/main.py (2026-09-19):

"""ESP32 BLE remote-key controller. Board-specific GPIOs drive optocouplers."""
import bluetooth
import ubinascii
import uhashlib
import os
import gc
import machine
import network
from security import Security
from machine import Pin
from micropython import const
from time import ticks_add, ticks_diff, ticks_ms, sleep_ms

# ESP32-S3 GPIO26/27 are reserved for flash/PSRAM.
IS_S3 = "ESP32S3" in os.uname().machine.upper().replace("-", "")
LOCK_PIN, UNLOCK_PIN, START_PIN, FIND_PIN = (4, 5, 6, 7) if IS_S3 else (26, 27, 25, 33)
PRESS_MS = 180
# Keep BLE connectable continuously; do not use machine sleep modes.
ADV_INTERVAL_US = 1000000
HEARTBEAT_MS = 30000
# Local pairing configuration is excluded from Git.
try:
    from pairing_config import BLE_PAIRING_SECRET
except ImportError:
    BLE_PAIRING_SECRET = "CHANGE_THIS_TO_A_LONG_RANDOM_SECRET"
BLE_DEVICE_NAME = "ESP32-Car-Remote"
SERVICE_UUID = bluetooth.UUID("6e400001-b5a3-f393-e0a9-e50e24dcca9e")
COMMAND_UUID = bluetooth.UUID("6e400002-b5a3-f393-e0a9-e50e24dcca9e")
LOG_UUID = bluetooth.UUID("6e400004-b5a3-f393-e0a9-e50e24dcca9e")
STATUS_UUID = bluetooth.UUID("6e400003-b5a3-f393-e0a9-e50e24dcca9e")
CONNECT, DISCONNECT, WRITE = const(1), const(2), const(3)
READ, WRITE_FLAG, NOTIFY = const(0x0002), const(0x0008), const(0x0010)

buttons = {"lock": Pin(LOCK_PIN, Pin.OUT, value=0), "unlock": Pin(UNLOCK_PIN, Pin.OUT, value=0), "start": Pin(START_PIN, Pin.OUT, value=0), "find": Pin(FIND_PIN, Pin.OUT, value=0)}
release_at = {name: None for name in buttons}
connections, authenticated, nonces = set(), set(), {}
receive_buffers = {}
security = Security(BLE_PAIRING_SECRET, ticks_ms, ticks_diff)
pending_disconnect = set()
packet_windows = {}

# Buffer diagnostics; never print from BLE callbacks or while a button is held.
log_queue = []
log_dropped = 0
log_history = []
log_streams = {}

def log(event, *fields):
    global log_dropped
    if event == "RX_FRAGMENT":
        return  # Packet details obscure user actions.
    if len(log_queue) < 64:
        log_queue.append((ticks_ms(), event, fields))
    else:
        log_dropped += 1

def describe_log(event, fields):
    names = {"lock": "锁车", "unlock": "解锁", "start": "启动（闪电键）", "find": "寻车（喇叭键）"}
    if event in ("COMMAND_RECEIVED", "BUTTON_ON", "BUTTON_OFF", "BUTTON_BUSY"):
        name = names.get(fields[0], "未知按键")
        if event == "COMMAND_RECEIVED":
            return "收到手机指令：" + name
        if event == "BUTTON_ON":
            return "正在模拟按下【%s】键，持续 %d 毫秒" % (name, PRESS_MS)
        if event == "BUTTON_OFF":
            return "【%s】按键已释放，输出已关闭（车辆状态未反馈）" % name
        return "暂未执行【%s】：上一次按键尚未释放，请稍后再试" % name
    if event == "SECURITY_TIMEOUT":
        return "连接验证超时或长期无操作，已断开连接，请重新连接"
    if event == "SECURITY_REJECT":
        return "指令校验失败或检测到重复指令，已拒绝执行并断开连接"
    if event == "BOOT":
        return "程序启动：%s，%s，复位原因代码 %s" % (fields[0], fields[1], fields[3])
    if event == "GPIO_READY":
        return "引脚就绪：锁车 GPIO%d，解锁 GPIO%d，启动 GPIO%d，寻车 GPIO%d；默认全部关闭" % (LOCK_PIN, UNLOCK_PIN, START_PIN, FIND_PIN)
    if event == "PAIRING_CONFIGURED":
        return "配对密钥已配置" if fields[0] else "尚未配置配对密钥，无法接受手机控制"
    if event == "POWER_SETTINGS":
        return "常连省电设置：Wi-Fi 已关闭，蓝牙每 1 秒广播，心跳每 30 秒输出"
    if event == "POWER_SETTINGS_FAILED":
        return "关闭 Wi-Fi 未成功，继续运行蓝牙；错误码：%s" % fields[0]
    if event == "BLE_ACTIVE":
        return "蓝牙已开启" if fields[0] else "蓝牙未开启"
    if event == "GATT_READY":
        return "蓝牙控制和日志服务已就绪"
    if event == "ADVERTISE_STARTED":
        return "已开启广播，等待手机连接：" + BLE_DEVICE_NAME
    if event == "CONNECTED":
        return "手机已连接，等待身份验证"
    if event == "DISCONNECTED":
        return "手机已断开，已清除认证状态"
    if event == "HELLO_RECEIVED":
        return "收到手机握手请求，开始验证身份"
    if event == "AUTH_OK":
        return "身份验证成功，现在可以锁车、解锁、启动或寻车"
    if event == "AUTH_FAILED":
        return "身份验证失败，请检查手机与 ESP32 的配对配置是否一致"
    if event == "STATUS":
        reasons = {"ERROR:NOT_CONFIGURED": "配对密钥未配置", "ERROR:AUTH_REQUIRED": "尚未通过身份验证", "ERROR:BUSY": "按键忙，请稍后重试", "ERROR:TOO_LONG": "指令过长", "ERROR:BAD_ENCODING": "指令编码错误", "ERROR:UNKNOWN_COMMAND": "无法识别的指令"}
        return "指令未执行：" + reasons.get(fields[-1], "未知状态")
    if event == "NOTIFY_FAILED":
        return "向手机发送状态失败，错误码：%s" % fields[-1]
    if event == "HEARTBEAT":
        return "运行正常｜蓝牙%s｜连接 %d 台，已验证 %d 台｜剩余内存 %d KB｜输出：锁车%s / 解锁%s / 启动%s / 寻车%s" % ("开启" if fields[1] else "关闭", fields[3], fields[5], fields[7] // 1024, "开" if fields[9] else "关", "开" if fields[10] else "关", "开" if fields[11] else "关", "开" if fields[12] else "关")
    return "诊断事件：" + event

def flush_logs():
    global log_dropped
    if any(deadline is not None for deadline in release_at.values()):
        return
    for _ in range(min(4, len(log_queue))):
        stamp, event, fields = log_queue.pop(0)
        line = "[设备计时 %d秒] %s" % (stamp // 1000, describe_log(event, fields))
        print(line)
        line = line[:240]
        log_history.append(line)
        if len(log_history) > 30:
            log_history.pop(0)
        for conn in tuple(authenticated):
            stream = log_streams.get(conn)
            if stream is None:
                continue
            if len(stream["lines"]) < 40:
                stream["lines"].append(line)
            else:
                stream["dropped"] += 1
    if log_dropped:
        print("[ESP32] 日志繁忙，已省略条数：", log_dropped)
        log_dropped = 0

def stream_logs():
    # One <=20-byte packet per connection per loop; control/pulse release wins.
    if any(deadline is not None for deadline in release_at.values()):
        return
    for conn in tuple(log_streams):
        if conn not in authenticated:
            log_streams.pop(conn, None)
            continue
        stream = log_streams[conn]
        if not stream["pending"]:
            if stream["dropped"]:
                stream["pending"] = ("[ESP32] 日志繁忙，已省略 %d 条\n" % stream["dropped"]).encode()
                stream["dropped"] = 0
            elif stream["lines"]:
                stream["pending"] = (stream["lines"].pop(0) + "\n").encode()
            else:
                continue
        try:
            ble.gatts_notify(conn, log_handle, stream["pending"][:20])
            stream["pending"] = stream["pending"][20:]
        except OSError:
            # Retry without recursive logging. Logs must never break control.
            pass

def digest(value):
    return ubinascii.hexlify(uhashlib.sha256(value.encode()).digest()).decode()

def advertise():
    name = BLE_DEVICE_NAME.encode()
    ble.gap_advertise(ADV_INTERVAL_US, adv_data=b"\x02\x01\x06" + bytes((len(name) + 1, 9)) + name)
    log("ADVERTISE_STARTED", "name=" + BLE_DEVICE_NAME, "interval_ms=", ADV_INTERVAL_US // 1000)

def status(value, conn=None):
    if value.startswith("ERROR:"):
        log("STATUS", "conn=", conn, "type=", value)
    payload = value.encode()
    ble.gatts_write(status_handle, payload)
    targets = (conn,) if conn is not None else tuple(connections)
    for target in targets:
        try:
            framed = payload + b"\n"
            for offset in range(0, len(framed), 20):
                ble.gatts_notify(target, status_handle, framed[offset:offset + 20])
        except OSError as error:
            log("NOTIFY_FAILED", "conn=", target, "errno=", error.args[0] if error.args else None)

def press(name):
    if any(value is not None for value in release_at.values()):
        log("BUTTON_BUSY", name)
        return False
    if release_at[name] is None:
        log("BUTTON_ON", name, "duration_ms=", PRESS_MS)
        buttons[name].on()
        release_at[name] = ticks_add(ticks_ms(), PRESS_MS)
        return True

def release_buttons():
    now = ticks_ms()
    for name, deadline in release_at.items():
        if deadline is not None and ticks_diff(now, deadline) >= 0:
            buttons[name].off()
            release_at[name] = None
            log("BUTTON_OFF", name)

def disconnect_client(conn):
    authenticated.discard(conn)
    log_streams.pop(conn, None)
    receive_buffers.pop(conn, None)
    packet_windows.pop(conn, None)
    security.close(conn)
    pending_disconnect.add(conn)

def check_connections():
    for conn in tuple(connections):
        if security.expired(conn) and conn not in pending_disconnect:
            log("SECURITY_TIMEOUT")
            disconnect_client(conn)
    for conn in tuple(pending_disconnect):
        try:
            ble.gap_disconnect(conn)
        except OSError:
            pass
        pending_disconnect.discard(conn)

def irq(event, data):
    if event == CONNECT:
        conn, _, _ = data
        if not security.open(conn):
            pending_disconnect.add(conn)
            return
        receive_buffers.pop(conn, None)
        log("CONNECTED", "conn=", conn)
        connections.add(conn); authenticated.discard(conn)
        nonces.pop(conn, None)
    elif event == DISCONNECT:
        conn, _, _ = data
        receive_buffers.pop(conn, None)
        log_streams.pop(conn, None)
        security.close(conn)
        pending_disconnect.discard(conn)
        packet_windows.pop(conn, None)
        log("DISCONNECTED", "conn=", conn)
        connections.discard(conn); authenticated.discard(conn); nonces.pop(conn, None); advertise()
    elif event == WRITE:
        conn, handle = data
        if handle != command_handle: return
        if conn not in connections or conn in pending_disconnect or security.expired(conn):
            disconnect_client(conn)
            return
        started, count = packet_windows.get(conn, (ticks_ms(), 0))
        if ticks_diff(ticks_ms(), started) >= 1000:
            started, count = ticks_ms(), 0
        packet_windows[conn] = (started, count + 1)
        if count >= 40:
            security.reject(conn)
            disconnect_client(conn)
            return
        chunk = ble.gatts_read(command_handle)
        pending = receive_buffers.get(conn, b"") + chunk
        log("RX_FRAGMENT", "conn=", conn, "bytes=", len(chunk), "buffered=", len(pending))
        if len(pending) > 128:
            receive_buffers.pop(conn, None)
            status("ERROR:TOO_LONG", conn)
            disconnect_client(conn)
            return
        while b"\n" in pending:
            line, pending = pending.split(b"\n", 1)
            try:
                handle_message(conn, line.decode().strip())
            except UnicodeError:
                status("ERROR:BAD_ENCODING", conn)
                disconnect_client(conn)
        if conn not in pending_disconnect:
            receive_buffers[conn] = pending

def handle_message(conn, message):
    if conn in pending_disconnect or security.expired(conn):
        disconnect_client(conn)
        return
    if message == "HELLO2":
        nonce = security.challenge(conn)
        if nonce is None:
            status("ERROR:AUTH_REQUIRED", conn)
            disconnect_client(conn)
            return
        log("HELLO_RECEIVED")
        status("CHALLENGE2:" + nonce, conn)
    elif message.startswith("AUTH2:"):
        if security.authenticate(conn, message[6:]):
            authenticated.add(conn)
            log("AUTH_OK")
            log_streams[conn] = {"lines": list(log_history), "pending": b"", "dropped": 0}
            status("AUTH_OK", conn)
        else:
            log("AUTH_FAILED")
            status("ERROR:AUTH_REQUIRED", conn)
            disconnect_client(conn)
    elif conn not in authenticated:
        status("ERROR:AUTH_REQUIRED", conn)
        disconnect_client(conn)
    else:
        name = security.command(conn, message)
        if name is None:
            log("SECURITY_REJECT")
            status("ERROR:AUTH_REQUIRED", conn)
            disconnect_client(conn)
            return
        log("COMMAND_RECEIVED", name)
        status("OK:" + name.upper() if press(name) else "ERROR:BUSY", conn)

try:
    network.WLAN(network.STA_IF).active(False)
    network.WLAN(network.AP_IF).active(False)
    log("POWER_SETTINGS")
except OSError as error:
    log("POWER_SETTINGS_FAILED", error.args[0] if error.args else None)

log("BOOT", os.uname().machine, "MicroPython=" + os.uname().release, "reset_cause=", machine.reset_cause())
log("GPIO_READY", "lock=", LOCK_PIN, "unlock=", UNLOCK_PIN, "start=", START_PIN, "find=", FIND_PIN, "levels=", buttons["lock"].value(), buttons["unlock"].value(), buttons["start"].value(), buttons["find"].value())
log("PAIRING_CONFIGURED", BLE_PAIRING_SECRET != "CHANGE_THIS_TO_A_LONG_RANDOM_SECRET")
ble = bluetooth.BLE(); ble.active(True)
log("BLE_ACTIVE", ble.active())
((command_handle, status_handle, log_handle),) = ble.gatts_register_services(((SERVICE_UUID, ((COMMAND_UUID, WRITE_FLAG), (STATUS_UUID, NOTIFY), (LOG_UUID, NOTIFY))),))
ble.gatts_set_buffer(command_handle, 128)
log("GATT_READY", "command_handle=", command_handle, "status_handle=", status_handle, "log_handle=", log_handle)
ble.irq(irq); status("READY"); advertise()
print("蓝牙服务已启动：", BLE_DEVICE_NAME)
heartbeat_at = ticks_add(ticks_ms(), HEARTBEAT_MS)
try:
    while True:
        release_buttons()
        check_connections()
        if ticks_diff(ticks_ms(), heartbeat_at) >= 0:
            log("HEARTBEAT", "ble=", ble.active(), "connections=", len(connections), "authenticated=", len(authenticated), "free_heap=", gc.mem_free(), "outputs=", buttons["lock"].value(), buttons["unlock"].value(), buttons["start"].value(), buttons["find"].value())
            heartbeat_at = ticks_add(ticks_ms(), HEARTBEAT_MS)
        flush_logs()
        stream_logs()
        sleep_ms(20)
finally:
    for button in buttons.values():
        button.off()

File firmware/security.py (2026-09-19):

"""Authenticated sessions and commands. No BLE or GPIO side effects."""
try:
    import uhashlib as hashlib
    import ubinascii as binascii
except ImportError:
    import hashlib, binascii
import os

def mac(key, message):
    key = key.encode() if isinstance(key, str) else key
    if len(key) > 64:
        key = hashlib.sha256(key).digest()
    key += b'\0' * (64 - len(key))
    inner = hashlib.sha256(bytes(x ^ 0x36 for x in key) + message.encode()).digest()
    return binascii.hexlify(hashlib.sha256(bytes(x ^ 0x5c for x in key) + inner).digest()).decode()

def equal(a, b):
    if len(a) != len(b):
        return False
    result = 0
    for x, y in zip(a.encode(), b.encode()):
        result |= x ^ y
    return result == 0

class Security:
    def __init__(self, key, now, diff):
        self.key, self.now, self.diff = key, now, diff
        self.sessions = {}
        self.failures = 0
        self.cooldown = None

    def open(self, conn):
        if self.cooldown is not None:
            if self.diff(self.now(), self.cooldown) < 30000:
                return False
            self.cooldown = None
            self.failures = 0
        if self.sessions:
            return False
        self.sessions[conn] = {'since': self.now(), 'last': self.now(), 'nonce': None, 'ok': False, 'seq': 0}
        return True

    def close(self, conn):
        self.sessions.pop(conn, None)

    def expired(self, conn):
        s = self.sessions.get(conn)
        return s is None or self.diff(self.now(), s['last'] if s['ok'] else s['since']) >= (300000 if s['ok'] else 15000)

    def challenge(self, conn):
        s = self.sessions.get(conn)
        if self.expired(conn) or s['nonce'] is not None or len(self.key) < 32 or self.key.startswith('CHANGE_THIS'):
            return None
        s['nonce'] = binascii.hexlify(os.urandom(16)).decode()
        return s['nonce']

    def reject(self, conn):
        self.close(conn)
        self.failures += 1
        if self.failures >= 5:
            self.cooldown = self.now()

    def authenticate(self, conn, proof):
        s = self.sessions.get(conn)
        if self.expired(conn) or not s['nonce'] or s['ok'] or not equal(mac(self.key, 'auth:v2:' + s['nonce']), proof):
            self.reject(conn)
            return False
        s['ok'] = True
        s['last'] = self.now()
        self.failures = 0
        return True

    def command(self, conn, message):
        s = self.sessions.get(conn)
        parts = message.split(':')
        if self.expired(conn) or not s['ok'] or len(parts) != 4 or parts[0] != 'CMD2':
            self.reject(conn)
            return None
        _, seq, name, proof = parts
        expected = s['seq'] + 1
        if expected > 2147483647 or seq != str(expected) or name not in ('LOCK', 'UNLOCK', 'START', 'FIND') or not equal(mac(self.key, 'cmd:v2:%s:%s:%s' % (s['nonce'], seq, name)), proof):
            self.reject(conn)
            return None
        # Consume even when GPIO is busy: a signed packet can execute at most once.
        s['seq'] = expected
        s['last'] = self.now()
        return name.lower()

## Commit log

2026-09-19 Sync latest secure BLE remote implementation
    [case-bottom.stl, case-lid.stl, case-photo-draft.scad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]
2026-09-19 Clarify phone-controlled trunk installation use case
